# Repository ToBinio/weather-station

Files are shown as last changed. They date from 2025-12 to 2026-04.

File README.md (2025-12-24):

# WeatherStation

## External Unit

### Sensors
- Temperature
- CO2
- Humidity
- Pressure
- Wind Speed
- Rainfall
- UV Index

### Features
- SolarPower
- HomeAssistant integration (mqtt)

## Indoor Unit

### Sensors
- Temperature
- CO2
- Humidity
- Volatile Organic Compounds (VOC / TVOC)
- Pressure
- Particulate Matter (PM1.0 / PM2.5 / PM10)

### Features
- Power plug
- Display
- HomeAssistant integration (mqtt)

## Shopping List
- [esp32](https://www.amazon.de/dp/B0D9BTQRYT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)
- [display](https://www.amazon.de/-/en/AZDelivery-HD44780-Bundle-Characters-Compatible/dp/B07JH6GHPR?s=ce-de)
- [pinHeaders](https://www.amazon.de/-/en/Breakaway-Connector-Soldering-Arduino-Prototype/dp/B0DRCL1MZ3)

### Sensors
- [SCD41(CO2)](https://www.amazon.de/dp/B0FK53SJHB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)
- [BME680(temp, humidity, pressure, VOC)](https://www.amazon.de/-/en/Development-CJMCU-680-Temperature-Interface-Compatible/dp/B0FPRC1FXW)

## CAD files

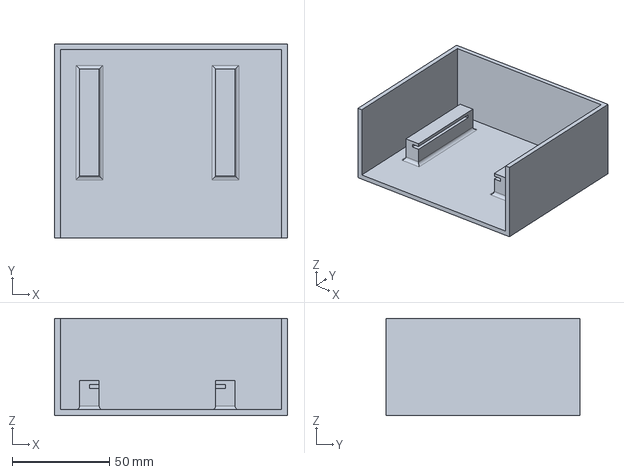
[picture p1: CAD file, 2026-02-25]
box/Unnamed.FCStd
120.0 x 100.0 x 50.0 mm

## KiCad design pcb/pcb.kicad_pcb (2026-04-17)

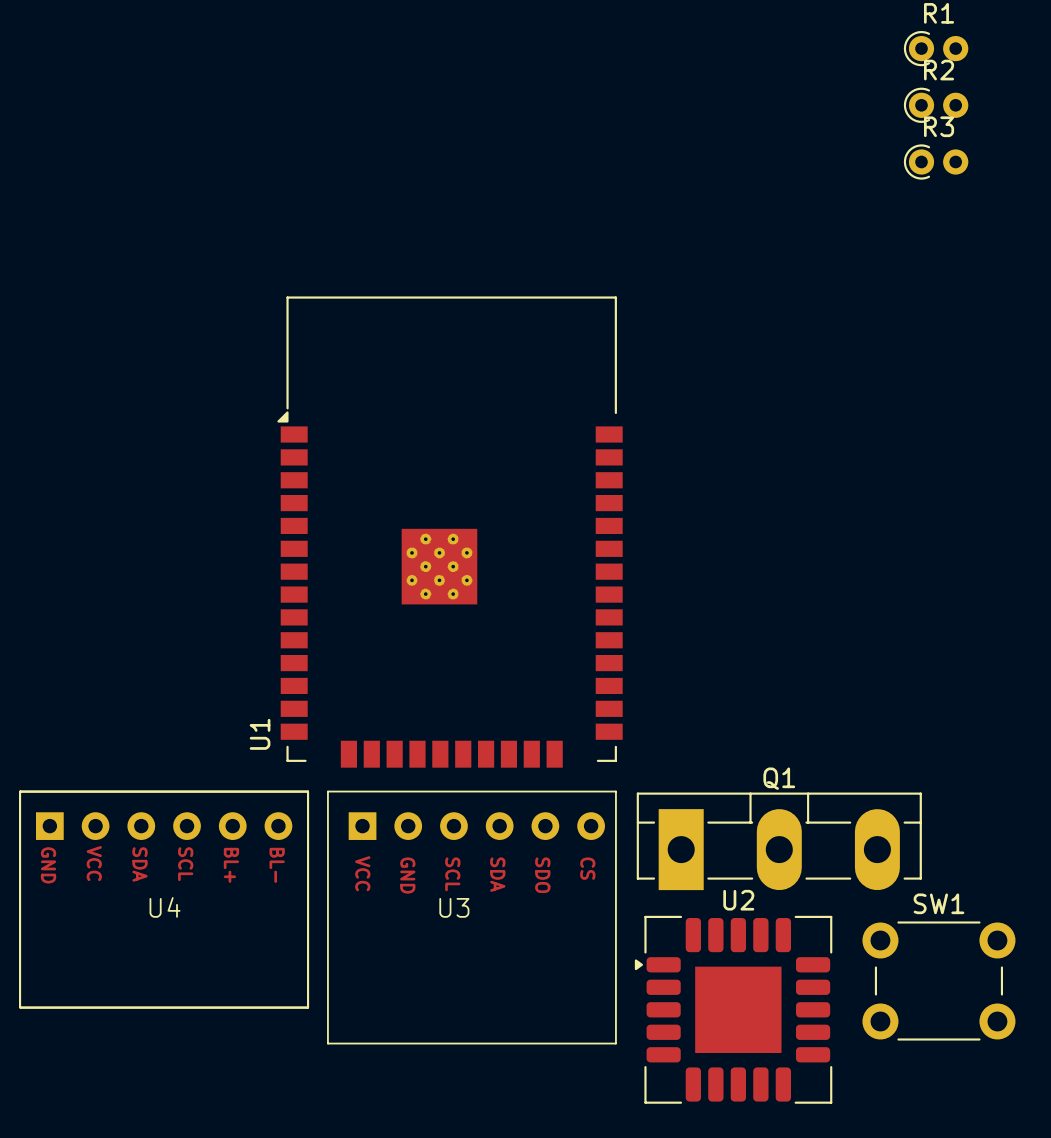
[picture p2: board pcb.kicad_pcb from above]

Board: 2 copper layers, 9 parts (0 on the bottom side), 12 nets, no tracks yet.

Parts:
Q1: PNP; TO-3P-3_Vertical
R1: R_Photo; R_Axial_DIN0204_L3.6mm_D1.6mm_P1.90mm_Vertical
R2: 1m; R_Axial_DIN0204_L3.6mm_D1.6mm_P1.90mm_Vertical
R3: 2k; R_Axial_DIN0204_L3.6mm_D1.6mm_P1.90mm_Vertical
SW1: SW_Push; SW_PUSH_6mm
U1: ESP32-WROOM-32
U2: SCD41-D-R2; Sensirion_SCD4x-1EP_10.1x10.1mm_P1.25mm_EP4.8x4.8mm
U3: BME680
U4: 1602A_LCD_I2C; LCD_I2C

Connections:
+3.3V: Q1.3 (E), R1.1, U2.7 (VDD), U2.19 (VDD), U3.1 (VCC)
+5V: U1.2 (VDD), U4.2 (VCC)
GND: R2.2, SW1.2, U1.1 (GND), U1.15 (GND), U1.38 (GND), U1.39 (GND), U2.6 (GND), U2.20 (GND), U2.21 (GND), U3.2 (GND), U4.1 (GND)
unnamed: Q1.2 (B), R3.2
unnamed: Q1.1 (C), U4.6 (BL-)
unnamed: R3.1, U1.31 (IO19)
unnamed: U1.33 (IO21), U2.10 (SDA), U3.4 (SDA)
unnamed: U1.36 (IO22), U2.9 (SCL), U3.3 (SCL)
unnamed: SW1.1, U1.37 (IO23)
unnamed: U1.10 (IO25), U4.3 (SDA)
unnamed: U1.11 (IO26), U4.4 (SCL)
unnamed: R1.2, R2.1, U1.8 (IO32)

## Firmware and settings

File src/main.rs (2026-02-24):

#![no_std]
#![no_main]
#![deny(
    clippy::mem_forget,
    reason = "mem::forget is generally not safe to do with esp_hal types, especially those \
    holding buffers for the duration of a data transfer."
)]
#![deny(clippy::unwrap_used)]

use alloc::string::ToString;
use bosch_bme680::{AsyncBme680, DeviceAddress};
use embassy_embedded_hal::shared_bus::asynch::i2c::I2cDevice;
use embassy_executor::Spawner;
use embassy_sync::blocking_mutex::raw::NoopRawMutex;
use embassy_sync::channel::{Channel, Receiver, Sender};
use embassy_sync::mutex::Mutex;
use embassy_time::{Delay, Duration, Timer};
use esp_backtrace as _;
use esp_hal::Async;
use esp_hal::analog::adc::{Adc, AdcConfig};
use esp_hal::clock::CpuClock;
use esp_hal::gpio::{Input, InputConfig};
use esp_hal::i2c::master::{Config as I2cConfig, I2c};
use esp_hal::mcpwm::operator::PwmPinConfig;
use esp_hal::mcpwm::{McPwm, PeripheralClockConfig};
use esp_hal::peripherals::{ADC1, GPIO19, GPIO23, GPIO32, MCPWM0, Peripherals};
use esp_hal::time::Rate;
use esp_hal::timer::timg::TimerGroup;
use lcd_lcm1602_i2c::async_lcd::Lcd;
use log::{info, warn};
use scd4x::Scd4xAsync;
use static_cell::StaticCell;
use weather_station::ha::{HaSensors, init_ha};
use weather_station::wifi::init_wifi;

extern crate alloc;

// This creates a default app-descriptor required by the esp-idf bootloader.
// For more information see: <https://docs.espressif.com/projects/esp-idf/en/stable/esp32/api-reference/system/app_image_format.html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>
esp_bootloader_esp_idf::esp_app_desc!();

#[derive(Debug)]
pub enum Events {
    BME680 {
        // Temperature in Celsius
        temp: f32,
        // Relative humidity in %
        humidity: f32,
        // Pressure in Pa
        pressure: f32,
        // Gas resistance in Ohms
        gas_resistance: f32,
    },
    SCD41 {
        // CO2 concentration in ppm
        co2: u16,
        // Temperature in Celsius
        temperature: f32,
        // Relative humidity in %
        humidity: f32,
    },
    ButtonPress,
}

type I2c1BusV33 = Mutex<NoopRawMutex, I2c<'static, Async>>;

type EventChannel = Channel<NoopRawMutex, Events, 1>;
type EventSender = Sender<'static, NoopRawMutex, Events, 1>;
type EventReceiver = Receiver<'static, NoopRawMutex, Events, 1>;

fn init_hardware() -> Peripherals {
    esp_println::logger::init_logger_from_env();

    let config = esp_hal::Config::default().with_cpu_clock(CpuClock::max());
    let peripherals = esp_hal::init(config);

    esp_alloc::heap_allocator!(#[esp_hal::ram(reclaimed)] size: 98768);

    peripherals
}

#[esp_rtos::main]
async fn main(spawner: Spawner) {
    let peripherals = init_hardware();

    let timg0 = TimerGroup::new(peripherals.TIMG0);
    esp_rtos::start(timg0.timer0);

    let stack = init_wifi(peripherals.WIFI, &spawner).await;
    info!("WiFi initialized!");

    let ha_sensors = init_ha(stack, &spawner);

    let i2c_v33 = I2c::new(peripherals.I2C0, I2cConfig::default())
        .expect("Failed to initialize I2C0")
        .with_scl(peripherals.GPIO22)
        .with_sda(peripherals.GPIO21)
        .into_async();
    static I2C_V33_BUS: StaticCell<I2c1BusV33> = StaticCell::new();
    let i2c_v33 = I2C_V33_BUS.init(Mutex::new(i2c_v33));

    let i2c_v5 = I2c::new(peripherals.I2C1, I2cConfig::default())
        .expect("Failed to initialize I2C1")
        .with_scl(peripherals.GPIO26)
        .with_sda(peripherals.GPIO25)
        .into_async();

    static CHANNEL: StaticCell<EventChannel> = StaticCell::new();
    let event_channel = CHANNEL.init(Channel::new());

    spawner
        .spawn(read_bme_680(i2c_v33, event_channel.sender()))
        .expect("Failed to spawn read_bme_680 task");
    spawner
        .spawn(read_scd_41(i2c_v33, event_channel.sender()))
        .expect("Failed to spawn read_scd_41 task");
    spawner
        .spawn(listen_button(peripherals.GPIO23, event_channel.sender()))
        .expect("Failed to spawn listen_button task");
    spawner
        .spawn(process_data(i2c_v5, ha_sensors, event_channel.receiver()))
        .expect("Failed to spawn process_data task");
    spawner
        .spawn(dim_lcd_backlight(
            peripherals.GPIO32,
            peripherals.ADC1,
            peripherals.GPIO19,
            peripherals.MCPWM0,
        ))
        .expect("Failed to spawn read_adc task");

    info!("Tasks initialized!");
}

async fn init_bme680(
    i2c_bus: &'static I2c1BusV33,
) -> AsyncBme680<I2cDevice<'static, NoopRawMutex, I2c<'static, Async>>, Delay> {
    let i2c = I2cDevice::new(i2c_bus);
    let mut sensor = AsyncBme680::new(i2c, DeviceAddress::Primary, Delay, 20);
    sensor
        .initialize(&bosch_bme680::Configuration::default())
        .await
        .expect("Failed to initialize BME680 sensor");

    sensor
}

#[embassy_executor::task]
async fn read_bme_680(i2c_bus: &'static I2c1BusV33, sender: EventSender) {
    let mut sensor = init_bme680(i2c_bus).await;

    loop {
        match sensor.measure().await {
            Ok(data) => {
                sender
                    .send(Events::BME680 {
                        temp: data.temperature,
                        humidity: data.humidity,
                        pressure: data.pressure,
                        gas_resistance: data.gas_resistance.unwrap_or(0.),
                    })
                    .await;
            }
            Err(err) => {
                warn!("Failed to read BME680 sensor - {:?}", err);
            }
        }

        Timer::after(Duration::from_secs(60)).await;
    }
}

async fn init_scd_41(
    i2c_bus: &'static I2c1BusV33,
) -> Scd4xAsync<I2cDevice<'static, NoopRawMutex, I2c<'static, Async>>, Delay> {
    let i2c = I2cDevice::new(i2c_bus);
    let mut sensor = Scd4xAsync::new(i2c, Delay);
    sensor.wake_up().await;
    sensor
        .stop_periodic_measurement()
        .await
        .expect("Failed to stop periodic measurement");
    sensor
        .reinit()
        .await
        .expect("Failed to reinitialize sensor");

    sensor
        .start_periodic_measurement()
        .await
        .expect("Failed to start periodic measurement");

    sensor
}

#[embassy_executor::task]
async fn read_scd_41(i2c_bus: &'static I2c1BusV33, sender: EventSender) {
    let mut sensor = init_scd_41(i2c_bus).await;

    loop {
        Timer::after(Duration::from_secs(5)).await;

        match sensor.measurement().await {
            Ok(data) => {
                sender
                    .send(Events::SCD41 {
                        co2: data.co2,
                        temperature: data.temperature,
                        humidity: data.humidity,
                    })
                    .await;
            }
            Err(err) => {
                warn!("Failed to read SCD41 sensor - {:?}", err);
            }
        }

        Timer::after(Duration::from_secs(55)).await;
    }
}

#[embassy_executor::task]
async fn listen_button(pin: GPIO23<'static>, sender: EventSender) {
    let mut button_pin = Input::new(
        pin,
        InputConfig::default().with_pull(esp_hal::gpio::Pull::Up),
    );

    loop {
        button_pin.wait_for_high().await;
        button_pin.wait_for_low().await;

        sender.send(Events::ButtonPress).await;
    }
}

struct Data {
    // Temperature in Celsius
    temp: f32,
    // Relative Humidity in percentage
    humidity: f32,
    // Pressure in hPa
    pressure: f32,
    // Gas Resistance in Ohms
    gas_resistance: f32,
    // CO2 concentration in ppm
    co2: u16,
}

enum DisplayMode {
    Temperature,
    Humidity,
    Pressure,
    GasResistance,
    CO2,
}

impl DisplayMode {
    async fn display(
        &self,
        data: &Data,
        lcd: &mut Lcd<'_, I2c<'static, Async>, Delay>,
    ) -> Result<(), esp_hal::i2c::master::Error> {
        let (header, value, unit) = match self {
            DisplayMode::Temperature => ("Temperature", &data.temp.to_string(), "C"),
            DisplayMode::Humidity => ("Humidity", &data.humidity.to_string(), "%"),
            DisplayMode::Pressure => ("Pressure", &data.pressure.to_string(), "hPa"),
            DisplayMode::CO2 => ("CO2", &data.co2.to_string(), "ppm"),
            DisplayMode::GasResistance => {
                ("Gas Resistance", &data.gas_resistance.to_string(), "Ohm")
            }
        };

        lcd.clear().await?;
        lcd.write_str(header).await?;
        lcd.set_cursor(1, 0).await?;
        lcd.write_str(value).await?;
        lcd.write_str(unit).await?;

        Ok(())
    }

    fn next(self) -> DisplayMode {
        match self {
            DisplayMode::Temperature => DisplayMode::Humidity,
            DisplayMode::Humidity => DisplayMode::Pressure,
            DisplayMode::Pressure => DisplayMode::GasResistance,
            DisplayMode::GasResistance => DisplayMode::CO2,
            DisplayMode::CO2 => DisplayMode::Temperature,
        }
    }
}

#[embassy_executor::task]
async fn dim_lcd_backlight(
    adc_pin: GPIO32<'static>,
    adc: ADC1<'static>,
    dim_pin: GPIO19<'static>,
    mcpwm: MCPWM0<'static>,
) {
    //configure PWM
    let clock_config = PeripheralClockConfig::with_frequency(Rate::from_mhz(40)).unwrap();
    let mut mcpw = McPwm::new(mcpwm, clock_config);
    mcpw.operator0.set_timer(&mcpw.timer0);

    let mut pwm_pin = mcpw
        .operator0
        .with_pin_a(dim_pin, PwmPinConfig::UP_ACTIVE_HIGH);

    mcpw.timer0.start(
        clock_config
            .timer_clock_with_frequency(
                99,
                esp_hal::mcpwm::timer::PwmWorkingMode::Increase,
                Rate::from_khz(20),
            )
            .expect("Failed to create timer config"),
    );

    //configure ADC
    let mut config = AdcConfig::new();
    let mut adc_pin = config.enable_pin(adc_pin, esp_hal::analog::adc::Attenuation::_11dB);
    let mut adc = Adc::new(adc, config);

    let mut smoothed_value = 0.5;
    loop {
        match adc.read_oneshot(&mut adc_pin) {
            Ok(value) => {
                let value = value as f32 / 4096.0;
                smoothed_value = (value + smoothed_value * 9.) / 10.;
                pwm_pin.set_timestamp((smoothed_value * 100.) as u16);
            }
            Err(nb::Error::WouldBlock) => {}
            Err(nb::Error::Other(err)) => {
                warn!("Failed to read ADC value - {:?}", err);
            }
        }

        Timer::after(Duration::from_millis(1000)).await;
    }
}

#[embassy_executor::task]
async fn process_data(
    mut i2c: I2c<'static, Async>,
    mut ha_sensors: HaSensors,
    receiver: EventReceiver,
) {
    let mut data = Data {
        temp: 0.0,
        humidity: 0.0,
        pressure: 0.0,
        gas_resistance: 0.0,
        co2: 0,
    };
    let mut mode = DisplayMode::Temperature;

    let mut delay = Delay;
    let mut lcd = Lcd::new(&mut i2c, &mut delay)
        .with_address(0x27)
        .with_cursor_on(false)
        .with_rows(2)
        .init()
        .await
        .expect("Failed to initialize LCD");

    mode.display(&data, &mut lcd)
        .await
        .expect("Failed to display initial mode");

    loop {
        match receiver.receive().await {
            Events::BME680 {
                temp,
                humidity,
                pressure,
                gas_resistance,
            } => {
                data.temp = temp;
                data.humidity = humidity;
                data.pressure = pressure / 100.0;
                data.gas_resistance = gas_resistance;

                ha_sensors.temperature.publish(data.temp);
                ha_sensors.humidity.publish(data.humidity);
                ha_sensors.pressure.publish(data.pressure);
                ha_sensors.gas_resistance.publish(data.gas_resistance);
            }
            Events::SCD41 { co2, .. } => {
                data.co2 = co2;

                ha_sensors.co2.publish(data.co2 as f32);
            }
            Events::ButtonPress => {
                mode = mode.next();
            }
        }

        if let Err(err) = mode.display(&data, &mut lcd).await {
            warn!("Failed to display mode: {}", err);
        };
    }
}

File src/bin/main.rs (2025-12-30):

#![no_std]
#![no_main]
#![deny(
    clippy::mem_forget,
    reason = "mem::forget is generally not safe to do with esp_hal types, especially those \
    holding buffers for the duration of a data transfer."
)]
#![deny(clippy::large_stack_frames)]

use embassy_executor::Spawner;
use embassy_time::{Duration, Timer};
use esp_backtrace as _;
use esp_hal::clock::CpuClock;
use esp_hal::timer::timg::TimerGroup;
use log::info;

extern crate alloc;

// This creates a default app-descriptor required by the esp-idf bootloader.
// For more information see: <https://docs.espressif.com/projects/esp-idf/en/stable/esp32/api-reference/system/app_image_format.html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>
esp_bootloader_esp_idf::esp_app_desc!();

#[allow(
    clippy::large_stack_frames,
    reason = "it's not unusual to allocate larger buffers etc. in main"
)]
#[esp_rtos::main]
async fn main(spawner: Spawner) -> ! {
    // generator version: 1.1.0

    esp_println::logger::init_logger_from_env();

    let config = esp_hal::Config::default().with_cpu_clock(CpuClock::max());
    let peripherals = esp_hal::init(config);

    esp_alloc::heap_allocator!(#[esp_hal::ram(reclaimed)] size: 98768);

    let timg0 = TimerGroup::new(peripherals.TIMG0);
    esp_rtos::start(timg0.timer0);

    info!("Embassy initialized!");

    let radio_init = esp_radio::init().expect("Failed to initialize Wi-Fi/BLE controller");
    let (mut _wifi_controller, _interfaces) =
        esp_radio::wifi::new(&radio_init, peripherals.WIFI, Default::default())
            .expect("Failed to initialize Wi-Fi controller");

    // TODO: Spawn some tasks
    let _ = spawner;

    loop {
        info!("Hello world!");
        Timer::after(Duration::from_secs(1)).await;
    }

    // for inspiration have a look at the examples at https://github.com/esp-rs/esp-hal/tree/esp-hal-v~1.0/examples
}

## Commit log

2025-12-26 add simple electric schematic
    [pcb.kicad_pcb, pcb.kicad_sch]
2025-12-26 add pullup resistors to design
    [pcb.kicad_sch]
2025-12-30 update pcb design to split 5v and 3.3v i2c devices
    [pcb.kicad_sch]
2025-12-30 dont commit pcb-backups
2025-12-31 blinking led
2025-12-31 read sensor data
    [pcb.kicad_sch]
2025-12-31 add button for selecting displayMode
    [pcb.kicad_sch]
2026-01-01 fix pressure unit
2026-01-10 add brighness reader
    [pcb.kicad_sch]
2026-01-14 basic setup pwm for backlight
    [pcb.kicad_sch]
2026-01-15 try dimming backlight via pwm
2026-01-15 fix PWM issues
2026-01-15 simplify schema by only using 3.3V
    [pcb.kicad_sch]
2026-01-17 Revert "simplify schema by only using 3.3V"
    This reverts commit 0584054847f7e7c6e520f649ccfa9b452367a544.
    [pcb.kicad_sch]
2026-01-17 working backlight dimming
    [pcb.kicad_sch]
2026-02-24 add basic box
    [Unnamed.FCStd]
2026-02-25 add holder vor main board
    [Unnamed.FCStd]
2026-04-17 start pcb setup
    [pcb.kicad_pcb, pcb.kicad_sch]
